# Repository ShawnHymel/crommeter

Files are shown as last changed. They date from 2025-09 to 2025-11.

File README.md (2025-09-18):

# Crommeter SAO

> SHOW ME WHAT YOU GOT

Badge accessory (SAO) to measure general sound level from cheers and applause. Gives a (somewhat) precise measurement of sound pressure level in dB.

This was made in Rust for no other reason than to test my embedded Rust skills.

## Build the Project

To build the project, you'll need Rust on your computer. Follow the [instructions here to install Rust](https://www.rust-lang.org/tools/install).

Next, install the Thumbv8m target processor:

```sh
rustup target add thumbv8m.main-none-eabihf
```

Navigate into the firmware directory and build the project:

```sh
cd firmware/crommeter/
cargo build --release
```

You can either flash the output ELF file (in *target/thumbv8m.main-none-eabihf/release*) using the [Raspberry Pi Debug Probe](https://www.raspberrypi.com/documentation/microcontrollers/debug-probe.html) or you can convert the ELF file to a UF2 file to flash over the USB mass storage device bootloader. To do the latter, you'll need to install [picotool](https://github.com/raspberrypi/picotool).

## (Optional) Install picotool

I recommend downloading one of the pre-compiled releases of picotool from [here](https://github.com/raspberrypi/pico-sdk-tools/releases). Unzip the file somewhere on your computer.

### Windows

Copy the *picotool/* folder to a place like *C:\Program Files\picotool\*.

Update PATH:

 1. Press **Win + R**, type `sysdm.cpl`, press **Enter**
 2. Go to the **Advanced** tab and click **Environment Variables**
 3. Under *User variables* or *System variables*, find *Path*
 4. Click **Edit > New** and add: `C:\Program Files\picotool`
 5. Click **OK** on all dialogs
 6. Restart your terminal/command prompt

### Linux

Copy picotool to your user local bin folder:

```sh
mkdir -p ~/.local/bin
cp picotool ~/.local/bin/
chmod +x ~/.local/bin/picotool
```

Update PATH: add the following to *~/.bashrc*:

```sh
export PATH="$HOME/.local/bin:$PATH"
```

Reload:

```sh
source ~/.bashrc
```

### macOS

Copy picotool to your user local bin folder:

```sh
mkdir -p ~/.local/bin
cp picotool ~/.local/bin/
chmod +x ~/.local/bin/picotool
```

Update PATH: add the following to *~/.zshrc*:

```sh
export PATH="$HOME/.local/bin:$PATH"
```

Reload:

```sh
source ~/.zshrc
```

## Run picotool and Flash

Once you have picotool installed, you can convert the ELF file to a UF2 file. Navigate to the firmware's directory and run:

```sh
cd firmware/crommeter/
picotool uf2 convert target/thumbv8m.main-none-eabihf/release/crommeter -t elf firmware.uf2
```

Hold the BOOT button on the RP2350 stamp and press/release the RESET button while the board is plugged into your computer. That should put the RP2350 into bootloader mode, which enumerates as a mass storage device on your computer. Then, simply copy the *firmware.uf2* file you just created to the RP2350 drive. The board should automatically reset and start running the firmware!

## License

The hardware files are released under [Creative Commons Attribution 4.0 International (CC BY 4.0)](https://creativecommons.org/licenses/by/4.0/).

Code in the firmware directory, unless otherwise noted, is licensed under the [Zero-Clause BSD license](https://opensource.org/license/0bsd) (0BSD).

```
Zero-Clause BSD
=============

Permission to use, copy, modify, and/or distribute this software for
any purpose with or without fee is hereby granted.

THE SOFTWARE IS PROVIDED “AS IS” AND THE AUTHOR DISCLAIMS ALL
WARRANTIES WITH REGARD TO THIS SOFTWARE INCLUDING ALL IMPLIED WARRANTIES
OF MERCHANTABILITY AND FITNESS. IN NO EVENT SHALL THE AUTHOR BE LIABLE
FOR ANY SPECIAL, DIRECT, INDIRECT, OR CONSEQUENTIAL DAMAGES OR ANY
DAMAGES WHATSOEVER RESULTING FROM LOSS OF USE, DATA OR PROFITS, WHETHER IN
AN ACTION OF CONTRACT, NEGLIGENCE OR OTHER TORTIOUS ACTION, ARISING OUT
OF OR IN CONNECTION WITH THE USE OR PERFORMANCE OF THIS SOFTWARE.
```

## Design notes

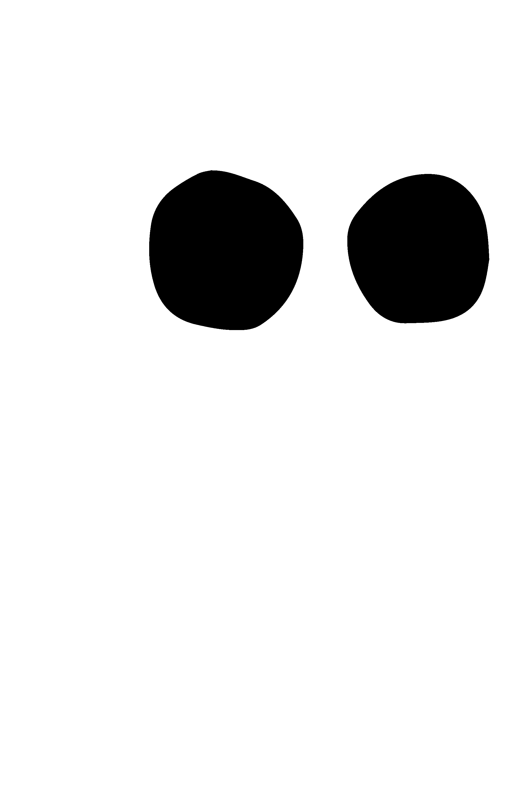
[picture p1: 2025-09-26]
hardware/artwork/cromulon-sm-keepout-bot.png

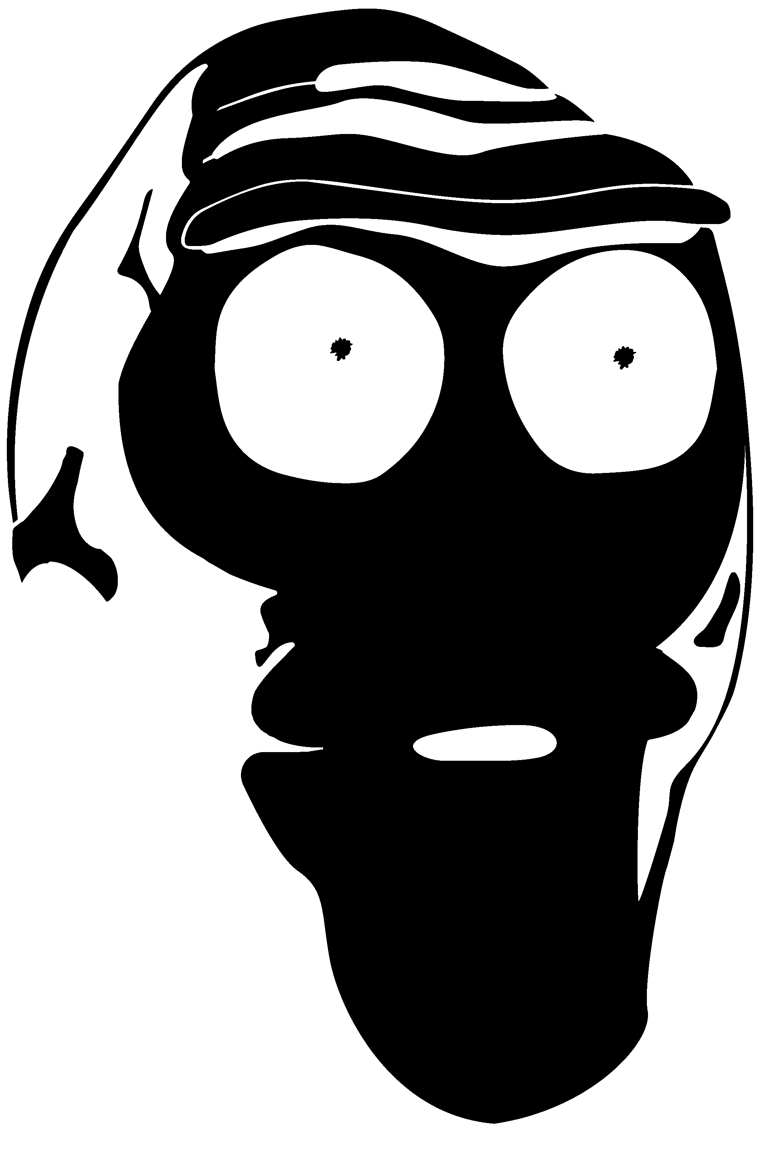
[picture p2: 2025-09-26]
hardware/artwork/cromulon-copper.png

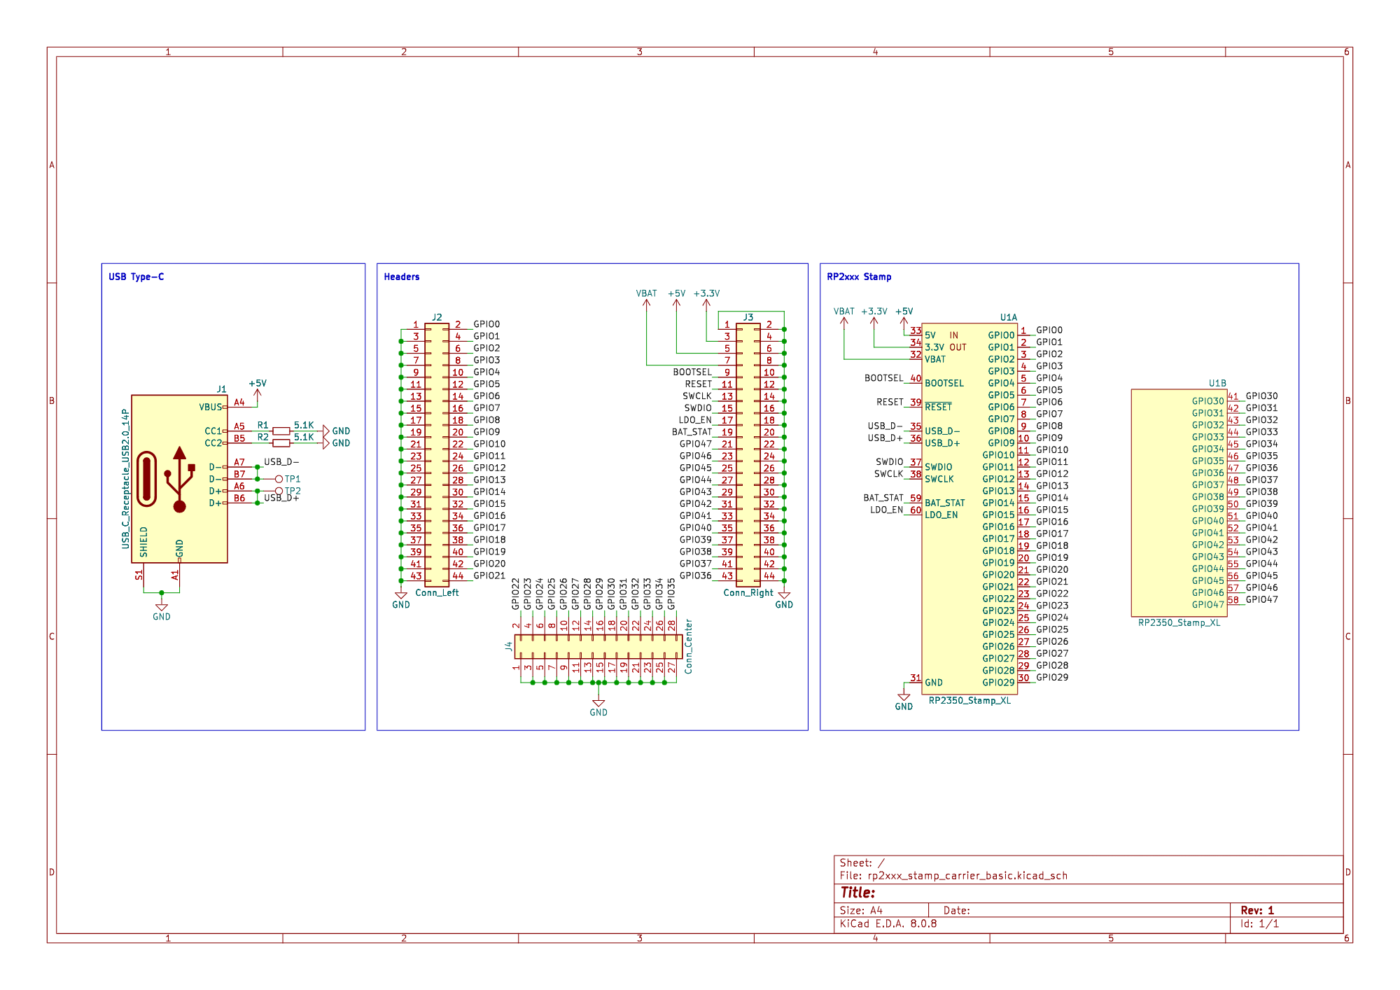
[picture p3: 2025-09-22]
references/rp2xxx-stamp-carrier-basic-schematic.png

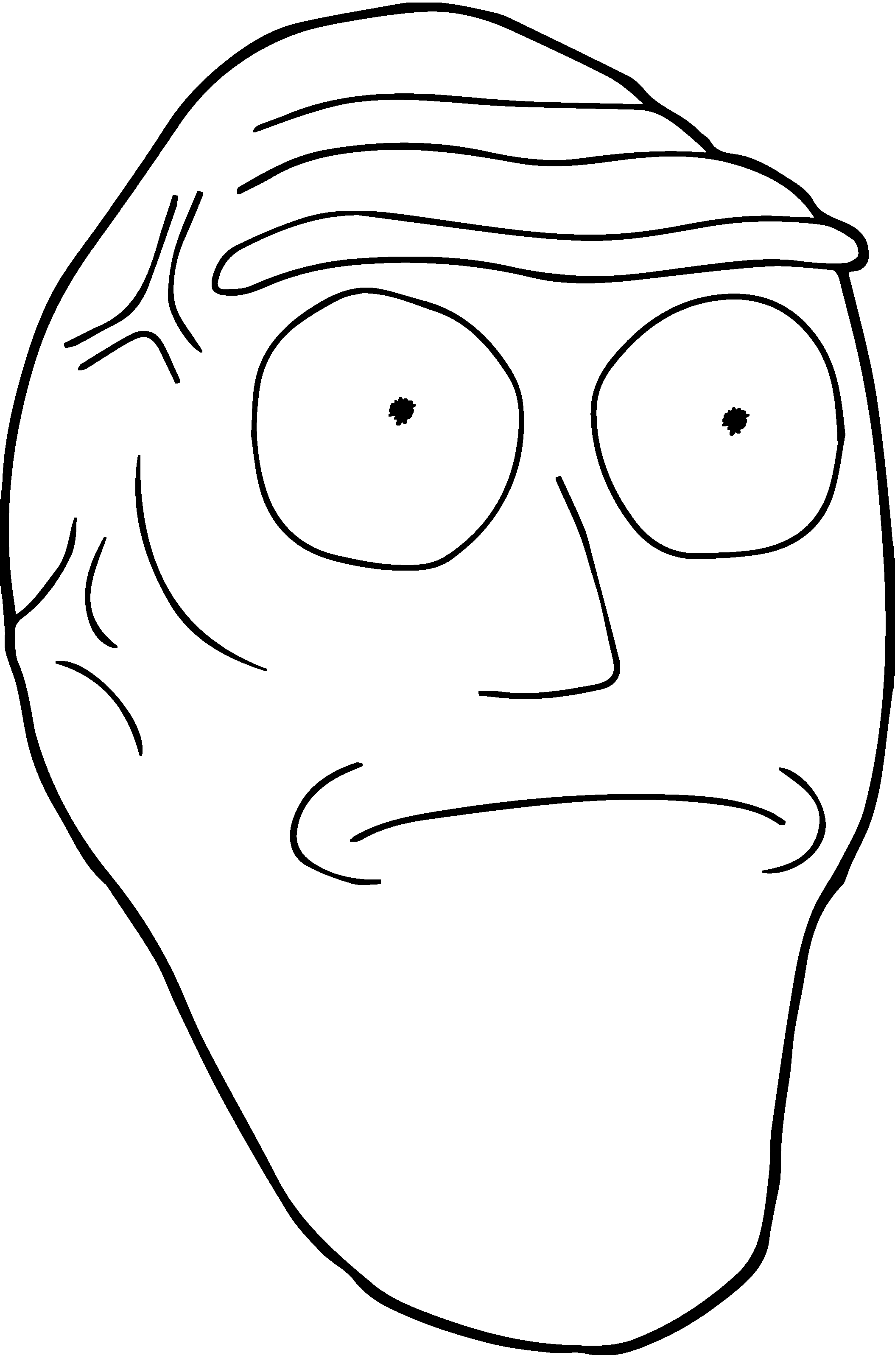
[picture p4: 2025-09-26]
hardware/artwork/cromulon-silkscreen.png

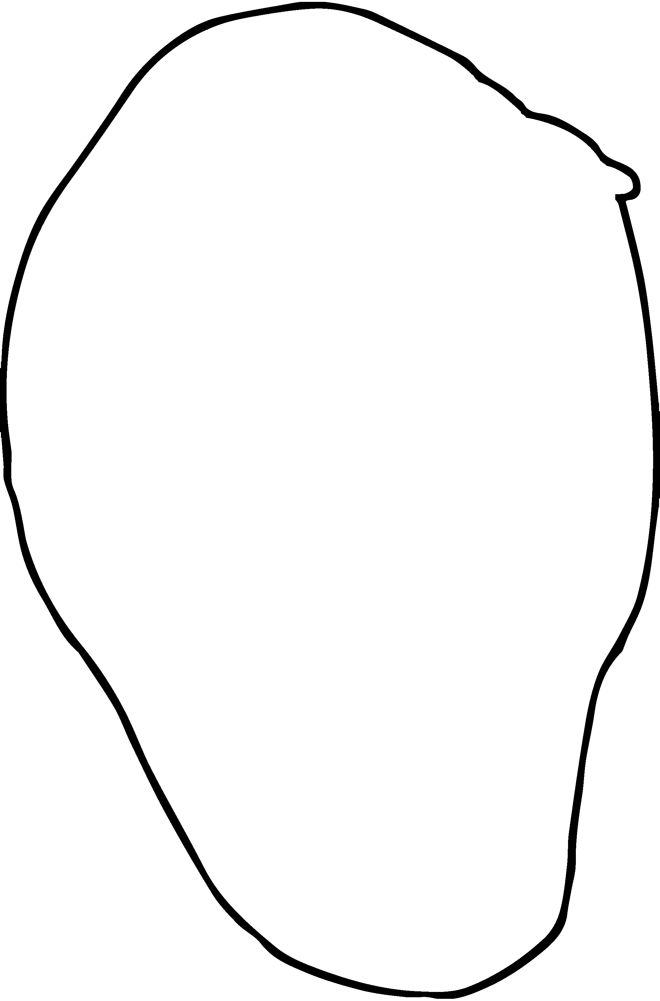
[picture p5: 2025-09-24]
hardware/artwork/cromulon-outline.png

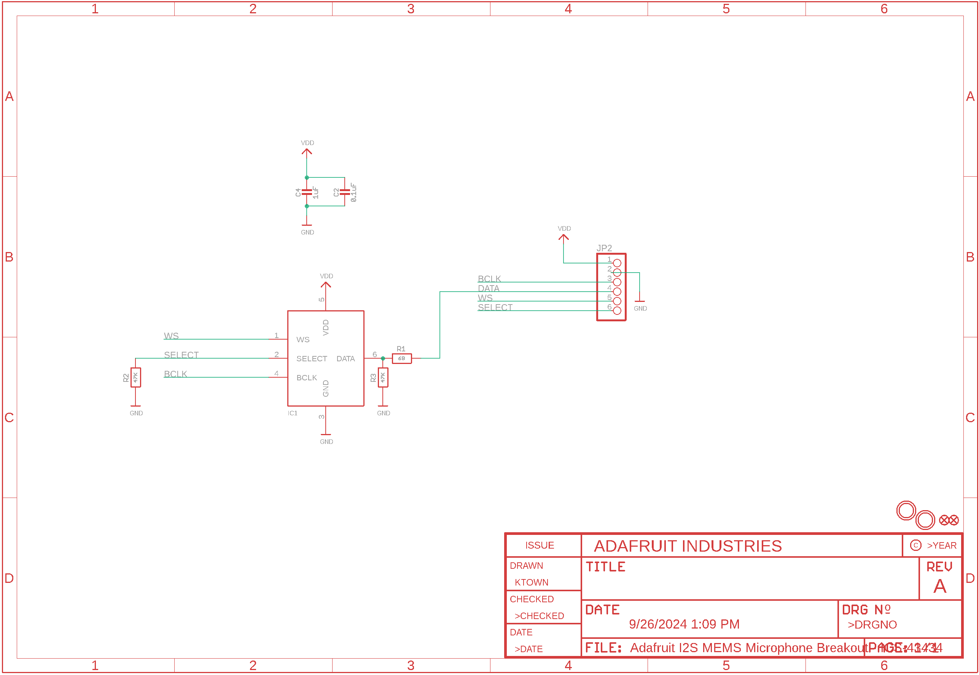
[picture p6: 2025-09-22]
references/adafruit-ics-43434-breakout-schematic.png

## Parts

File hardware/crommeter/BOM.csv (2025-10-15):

Reference | Qty | Value | Footprint | MANUFACTURER | Manufacturer Part Number | Part Link | Footprint Link
C1 | 1 | 0.1uF | Capacitor_SMD:C_0603_1608Metric_Pad1.08x0.95mm_HandSolder | YAGEO | CC0603KRX7R7BB104 | https://www.digikey.com/en/products/detail/yageo/CC0603KRX7R7BB104/302822
C2 | 1 | 1uF | Capacitor_SMD:C_0603_1608Metric_Pad1.08x0.95mm_HandSolder | YAGEO | CC0603KRX7R7BB105 | https://www.digikey.com/en/products/detail/yageo/CC0603KRX7R7BB105/2833611
D1,D2,D3,D4,D5,D6,D7,D8 | 8 | CUW_Y3SH.B2-GFJD-5J6T-Z242-20-R18-Z | CUW_Y3SH_B2_GFJD_5J6T_Z242_20_R18_Z:LED_CUW_Y3SH.B2-GFJD-5J6T-Z242-20-R18-Z | OSRAM Opto Semiconductors Inc. | CUW Y3SH.B2-GFJD-5J6T-Z242-20-R18-Z | https://www.digikey.com/en/products/detail/ams-osram-usa-inc/CUW-Y3SH-B2-GFJD-5J6T-Z242-20-R18-Z/13998110 | https://www.digikey.com/en/models/13998110
H1 | 1 | MountingHole | MountingHole:MountingHole_4.3mm_M4
J1 | 1 | 10118194-0001LF | 10118194_0001LF:AMPHENOL_10118194-0001LF | Amphenol | 10118194-0001LF | https://www.digikey.com/en/products/detail/amphenol-cs-fci/10118194-0001LF/2785389 | https://www.digikey.com/en/models/2785389
J2 | 1 | Conn_01x03_Pin | 10129380-903001BLF:AMPHENOL_10129380-903001BLF | Amphenol ICC (FCI) | 10129380-903001BLF | https://www.digikey.com/en/products/detail/amphenol-cs-fci/10129380-903001BLF/7916034 | https://www.digikey.com/en/models/7916034
J3 | 1 | PRT-14417 | qwiic_connector:CONN_PRT-14417_SPK | SparkFun Electronics | 14417 | https://www.digikey.com/en/products/detail/sparkfun-electronics/14417/7652746 | https://www.digikey.com/en/models/7652746
MK1 | 1 | ICS-43434 | Sensor_Audio:InvenSense_ICS-43434-6_3.5x2.65mm | TDK InvenSense | ICS-43434 | https://www.digikey.com/en/products/detail/tdk-invensense/ICS-43434/6140298 | https://www.digikey.com/en/models/6140298
P1 | 1 | S2B-PH-SM4-TB | S2B-PH-SM4-TB:JST_S2B-PH-SM4-TB | JST | S2B-PH-SM4-TB | https://www.digikey.com/en/products/detail/jst-sales-america-inc/S2B-PH-SM4-TB/926655 | https://www.digikey.com/en/models/926655
Q1,Q2,Q3 | 3 | BSD840NH6327XTSA1 | BSD840NH6327XTSA1:TRANS_BSD840NH6327XTSA1 | INFINEON | BSD840NH6327XTSA1 | https://www.digikey.com/en/products/detail/infineon-technologies/BSD840NH6327XTSA1/2783455 | https://www.digikey.com/en/models/2783455
R1 | 1 | 47k | Resistor_SMD:R_0603_1608Metric_Pad0.98x0.95mm_HandSolder | YAGEO | RC0603FR-0747KL | https://www.digikey.com/en/products/detail/yageo/RC0603FR-0747KL/727253
R2 | 1 | 68 | Resistor_SMD:R_0603_1608Metric_Pad0.98x0.95mm_HandSolder | YAGEO | RC0603FR-0768RL | https://www.digikey.com/en/products/detail/yageo/RC0603FR-0768RL/727351
R3,R4,R5,R6,R7,R8,R9,R10 | 8 | 120 | Resistor_SMD:R_0603_1608Metric_Pad0.98x0.95mm_HandSolder | YAGEO | RC0603JR-7W120RL | https://www.digikey.com/en/products/detail/yageo/RC0603JR-7W120RL/12698837
R11,R13,R15,R21,R27 | 5 | 100 | Resistor_SMD:R_0603_1608Metric_Pad0.98x0.95mm_HandSolder | YAGEO | RC0603FR-7W100RL | https://www.digikey.com/en/products/detail/yageo/RC0603FR-7W100RL/12698887
R12,R14,R16,R22,R28 | 5 | 100k | Resistor_SMD:R_0603_1608Metric_Pad0.98x0.95mm_HandSolder | YAGEO | RC0603FR-07100KL | https://www.digikey.com/en/products/detail/yageo/RC0603FR-07100KL/726889
R17,R18,R19,R20,R23,R24,R25,R26 | 8 | 47 | Resistor_SMD:R_0603_1608Metric_Pad0.98x0.95mm_HandSolder | YAGEO | RC0603FR-1347RL | https://www.digikey.com/en/products/detail/yageo/RC0603FR-1347RL/13694193
R29,R30,R31 | 3 | DNP | Resistor_SMD:R_0603_1608Metric_Pad0.98x0.95mm_HandSolder
SW1 | 1 | SW_Push_Dual | FSM2JSMAATR:SWITCH_FSM2JSMAA_TYC | TE Connectivity ALCOSWITCH Switches | FSM2JSMAATR | https://www.digikey.com/en/products/detail/te-connectivity-alcoswitch-switches/FSM2JSMAATR/1201469 | https://www.digikey.com/en/models/1201469
U1 | 1 | RP2350_Stamp | RP2xxx_Stamp:RP2xxx_Stamp_SMD | Solder Party | RP2350 Stamp | https://shop.pimoroni.com/products/rp2350-stamp | https://github.com/solderparty/rp2xxx_stamp_footprints
U2 | 1 | Common Cathode | custom:SDTx40R2W | ChromeLED | SDTC40R2W | https://www.digikey.com/en/products/detail/chromeled/SDTC40R2W/12698561
X1 | 1 | Badgelife_sao_connector_v169bis | badgelife_sao_v169bis:Badgelife-SAOv169-SAO-2x3 | Adam Tech | BHR-06-VUA | https://www.digikey.com/en/products/detail/adam-tech/BHR-06-VUA/10414837 | https://cdn.hackaday.io/files/1751827494986688/KiCad_SAOv2.zip

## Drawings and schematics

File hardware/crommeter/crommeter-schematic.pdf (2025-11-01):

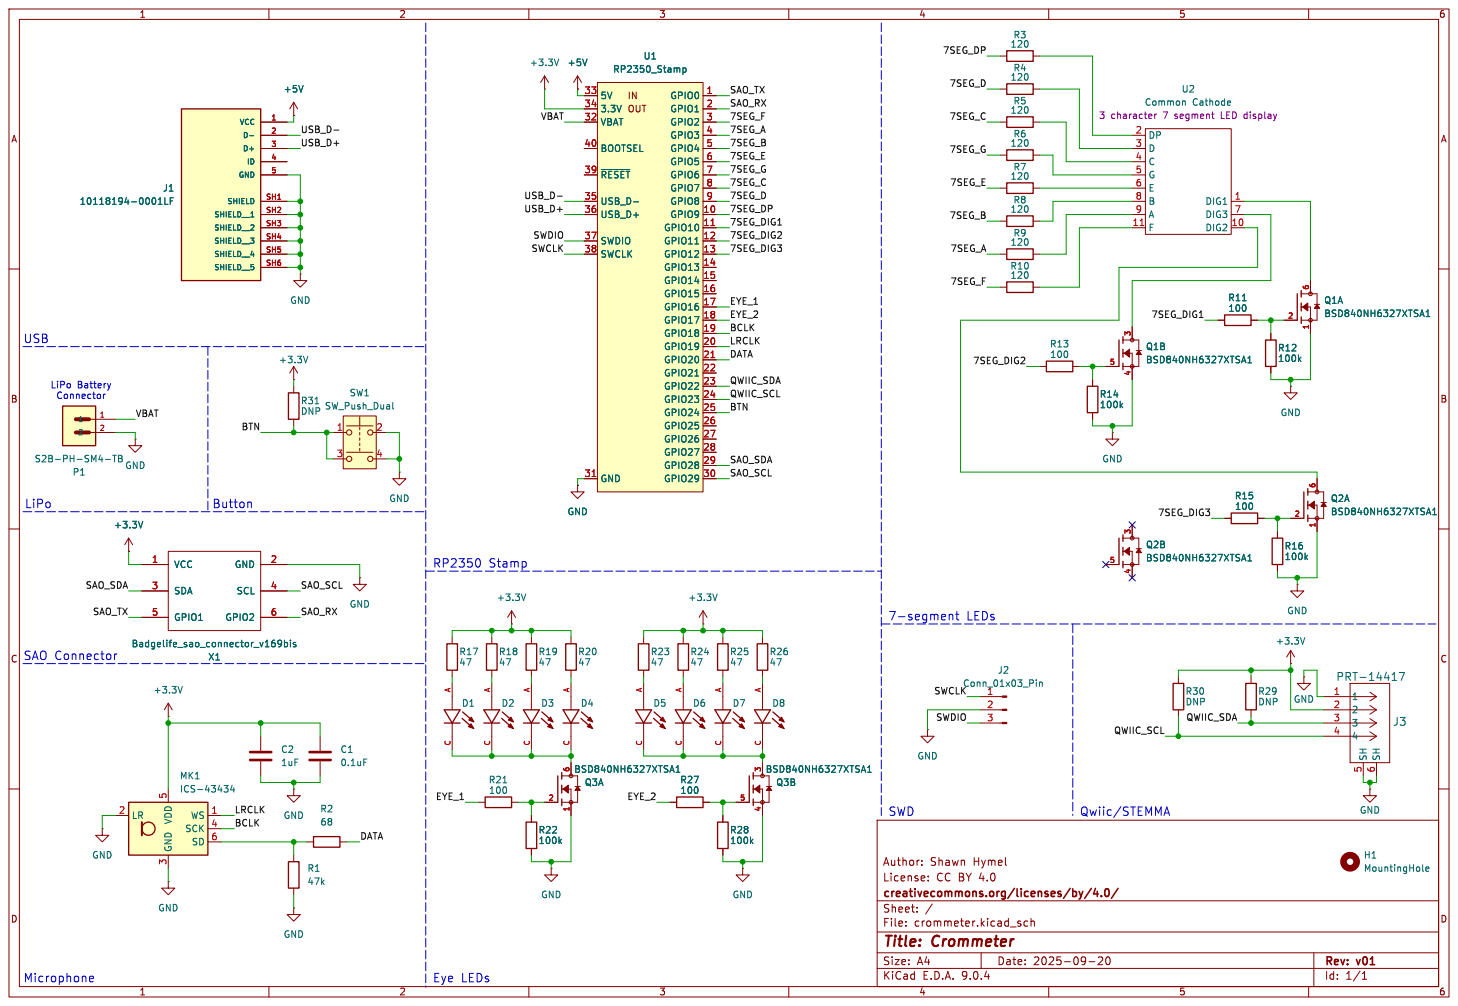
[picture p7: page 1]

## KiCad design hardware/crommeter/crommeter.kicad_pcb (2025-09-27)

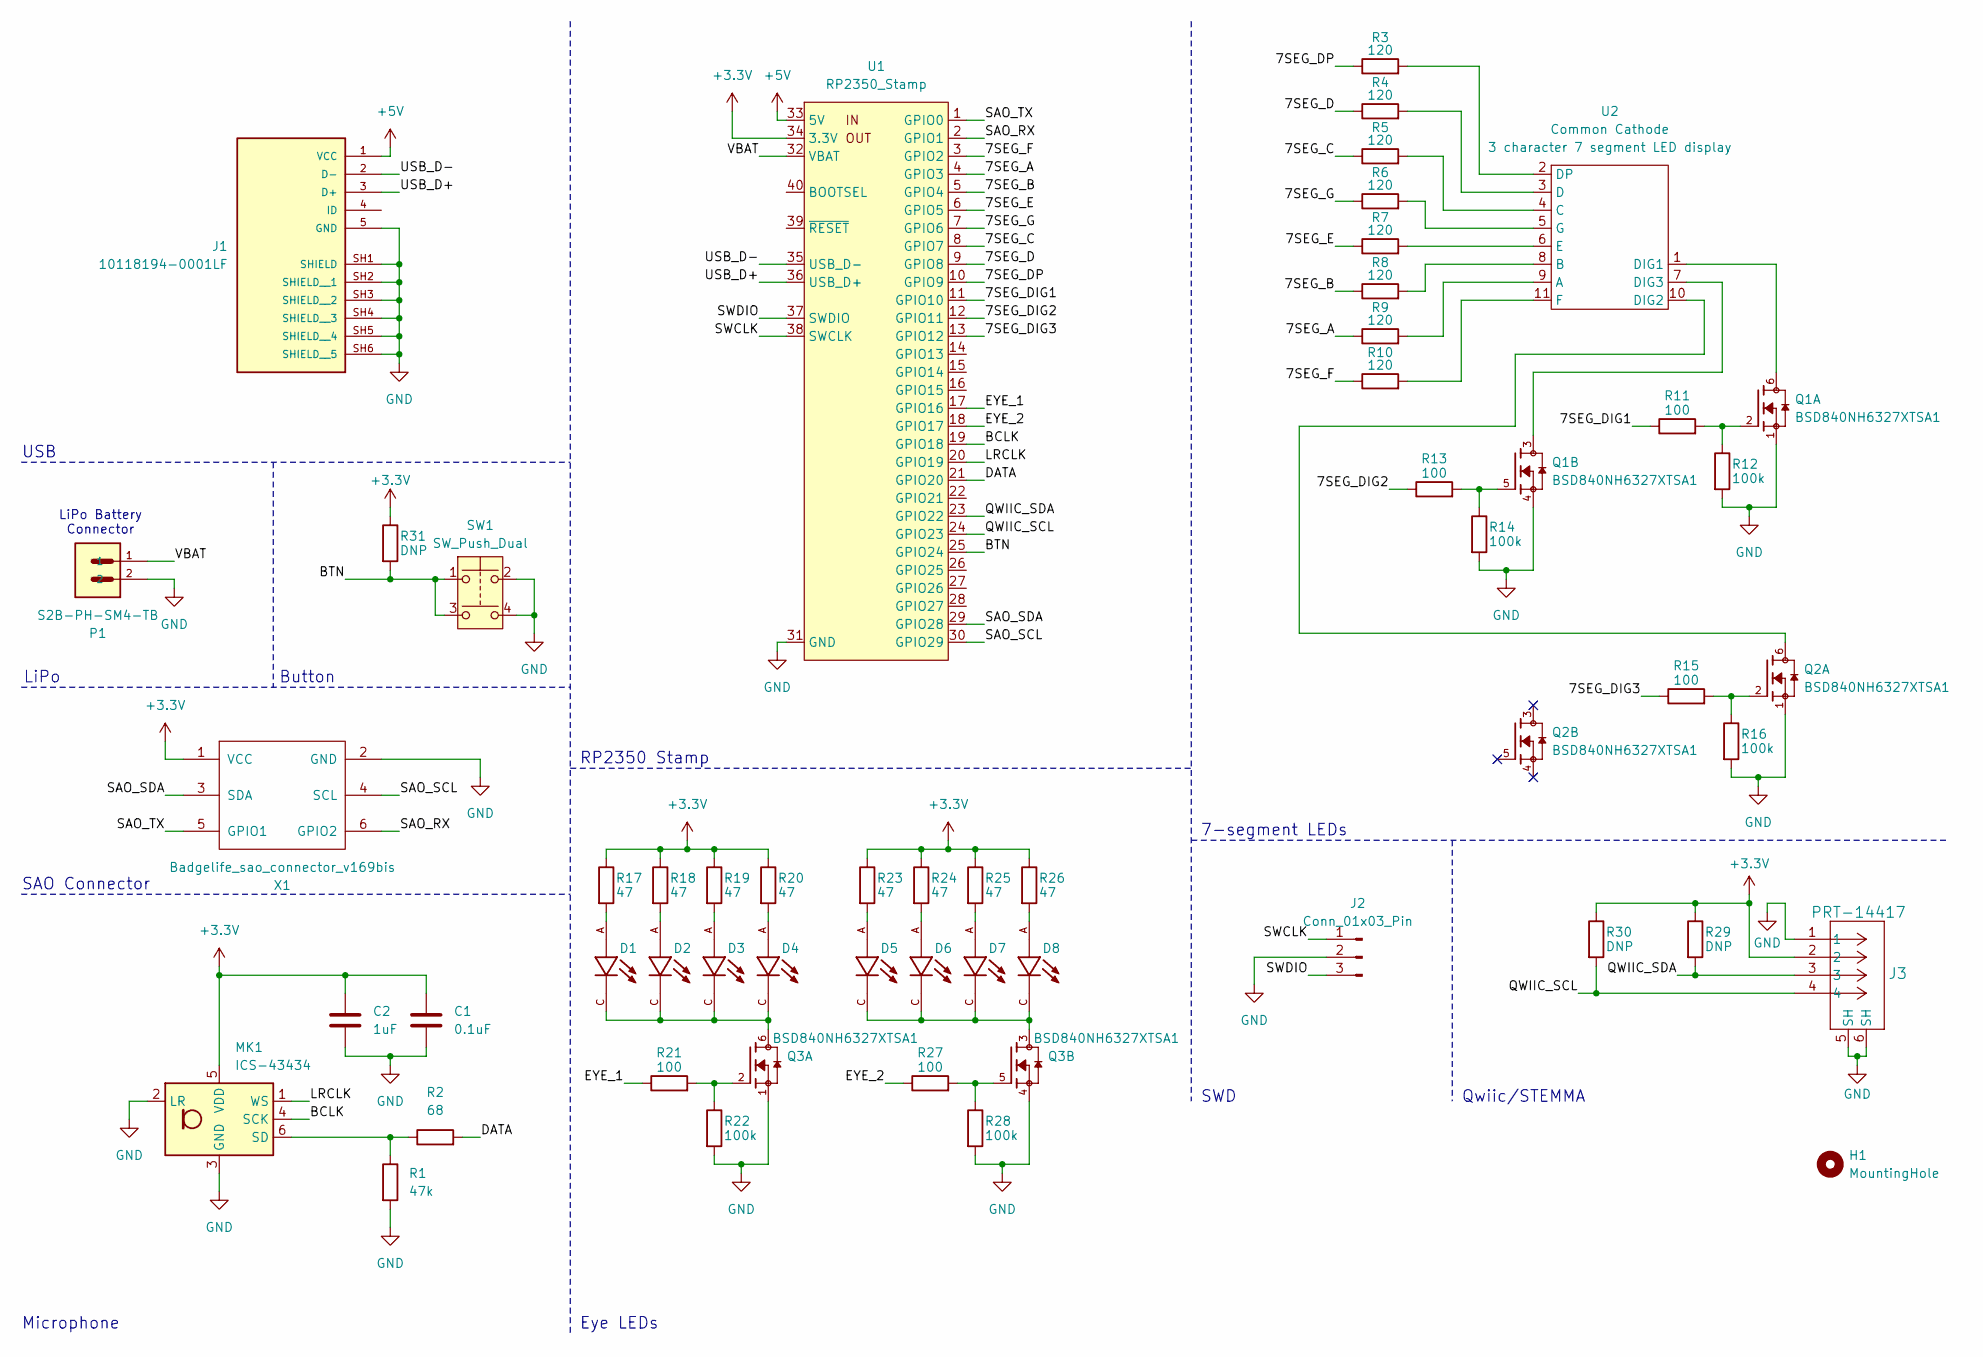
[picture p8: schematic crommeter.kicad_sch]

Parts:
C1: 0.1uF; C_0603_1608Metric_Pad1.08x0.95mm_HandSolder
C2: 1uF; C_0603_1608Metric_Pad1.08x0.95mm_HandSolder
D1, D2, D3, D4, D5, D6, D7, D8: CUW_Y3SH.B2-GFJD-5J6T-Z242-20-R18-Z; LED_CUW_Y3SH.B2-GFJD-5J6T-Z242-20-R18-Z; PARTREV 1.0
H1: MountingHole; MountingHole_4.3mm_M4
J1: 10118194-0001LF; AMPHENOL_10118194-0001LF; PARTREV D
J2: Conn_01x03_Pin; AMPHENOL_10129380-903001BLF
J3: PRT-14417; CONN_PRT-14417_SPK
MK1: ICS-43434; InvenSense_ICS-43434-6_3.5x2.65mm
P1: S2B-PH-SM4-TB; JST_S2B-PH-SM4-TB
Q1, Q2, Q3: BSD840NH6327XTSA1; TRANS_BSD840NH6327XTSA1; PARTREV 2.4
R1: 47k; R_0603_1608Metric_Pad0.98x0.95mm_HandSolder
R2: 68; R_0603_1608Metric_Pad0.98x0.95mm_HandSolder
R3, R4, R5, R6, R7, R8, R9, R10: 120; R_0603_1608Metric_Pad0.98x0.95mm_HandSolder
R11, R13, R15, R21, R27: 100; R_0603_1608Metric_Pad0.98x0.95mm_HandSolder
R12, R14, R16, R22, R28: 100k; R_0603_1608Metric_Pad0.98x0.95mm_HandSolder
R17, R18, R19, R20, R23, R24, R25, R26: 47; R_0603_1608Metric_Pad0.98x0.95mm_HandSolder
R29, R30, R31: DNP; R_0603_1608Metric_Pad0.98x0.95mm_HandSolder
SW1: SW_Push_Dual; SWITCH_FSM2JSMAA_TYC
U1: RP2350_Stamp; RP2xxx_Stamp_SMD
U2: Common Cathode; SDTx40R2W
X1: Badgelife_sao_connector_v169bis; Badgelife-SAOv169-SAO-2x3

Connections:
+3.3V: C1.1, C2.1, J3.2, MK1.5 (VDD), R17.1, R18.1, R19.1, R20.1, R23.1, R24.1, R25.1, R26.1, R29.1, R30.1, R31.1, U1.34 (3.3V), X1.1 (VCC)
+5V: J1.1 (VCC), U1.33 (5V)
/7SEG_A: R9.1, U1.4 (GPIO3)
/7SEG_B: R8.1, U1.5 (GPIO4)
/7SEG_C: R5.1, U1.8 (GPIO7)
/7SEG_D: R4.1, U1.9 (GPIO8)
/7SEG_DIG1: R11.1, U1.11 (GPIO10)
/7SEG_DIG2: R13.1, U1.12 (GPIO11)
/7SEG_DIG3: R15.1, U1.13 (GPIO12)
/7SEG_DP: R3.1, U1.10 (GPIO9)
/7SEG_E: R7.1, U1.6 (GPIO5)
/7SEG_F: R10.1, U1.3 (GPIO2)
/7SEG_G: R6.1, U1.7 (GPIO6)
/<NO NET>: U1.29 (GPIO28), X1.3 (SDA)
/BCLK: MK1.4 (SCK), U1.19 (GPIO18)
/BTN: R31.2, SW1.1, SW1.3, U1.25 (GPIO24)
/DATA: R2.2, U1.21 (GPIO20)
/EYE_1: R21.1, U1.17 (GPIO16)
/EYE_2: R27.1, U1.18 (GPIO17)
/LRCLK: MK1.1 (WS), U1.20 (GPIO19)
/QWIIC_SCL: J3.4, R30.2, U1.24 (GPIO23)
/QWIIC_SDA: J3.3, R29.2, U1.23 (GPIO22)
/SAO_RX: U1.2 (GPIO1), X1.6 (GPIO2)
/SAO_SCL: U1.30 (GPIO29), X1.4 (SCL)
/SAO_TX: U1.1 (GPIO0), X1.5 (GPIO1)
/SWCLK: J2.1, U1.38 (SWCLK)
/SWDIO: J2.3, U1.37 (SWDIO)
/USB_D+: J1.3 (D+), U1.36 (USB_D+)
/USB_D-: J1.2 (D-), U1.35 (USB_D-)
/VBAT: P1.1, U1.32 (VBAT)
GND: C1.2, C2.2, J1.5 (GND), J1.SH1 (SHIELD), J1.SH2 (SHIELD__1), J1.SH3 (SHIELD__2), J1.SH4 (SHIELD__3), J1.SH5 (SHIELD__4), J1.SH6 (SHIELD__5), J2.2, J3.1, J3.5 (SH), J3.6 (SH), MK1.2 (LR), MK1.3 (GND), P1.2, Q1.1, Q1.4, Q2.1, Q3.1, Q3.4, R1.2, R12.2, R14.2, R16.2, R22.2, R28.2, SW1.2, SW1.4, U1.31 (GND), X1.2 (GND)
unnamed: D1.A, R17.2
unnamed: D1.C, D2.C, D3.C, D4.C, Q3.6
unnamed: D2.A, R18.2
unnamed: D3.A, R19.2
unnamed: D4.A, R20.2
unnamed: D5.A, R23.2
unnamed: D5.C, D6.C, D7.C, D8.C, Q3.3
unnamed: D6.A, R24.2
unnamed: D7.A, R25.2
unnamed: D8.A, R26.2
unnamed: MK1.6 (SD), R1.1, R2.1
unnamed: Q1.2, R11.2, R12.1
unnamed: Q1.5, R13.2, R14.1
unnamed: Q2.2, R15.2, R16.1
unnamed: Q3.2, R21.2, R22.1
unnamed: Q3.5, R27.2, R28.1
unnamed: R9.2, U2.9 (A)
unnamed: R8.2, U2.8 (B)
unnamed: R5.2, U2.4 (C)
unnamed: R4.2, U2.3 (D)
unnamed: Q1.6, U2.1 (DIG1)
unnamed: Q2.6, U2.10 (DIG2)
unnamed: Q1.3, U2.7 (DIG3)
unnamed: R3.2, U2.2 (DP)
unnamed: R7.2, U2.6 (E)
unnamed: R10.2, U2.11 (F)
unnamed: R6.2, U2.5 (G)

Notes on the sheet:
7-segment LEDs
RP2350 Stamp
Microphone
USB
LiPo Battery Connector
Eye LEDs
Button
Qwiic/STEMMA
LiPo
SAO Connector
SWD

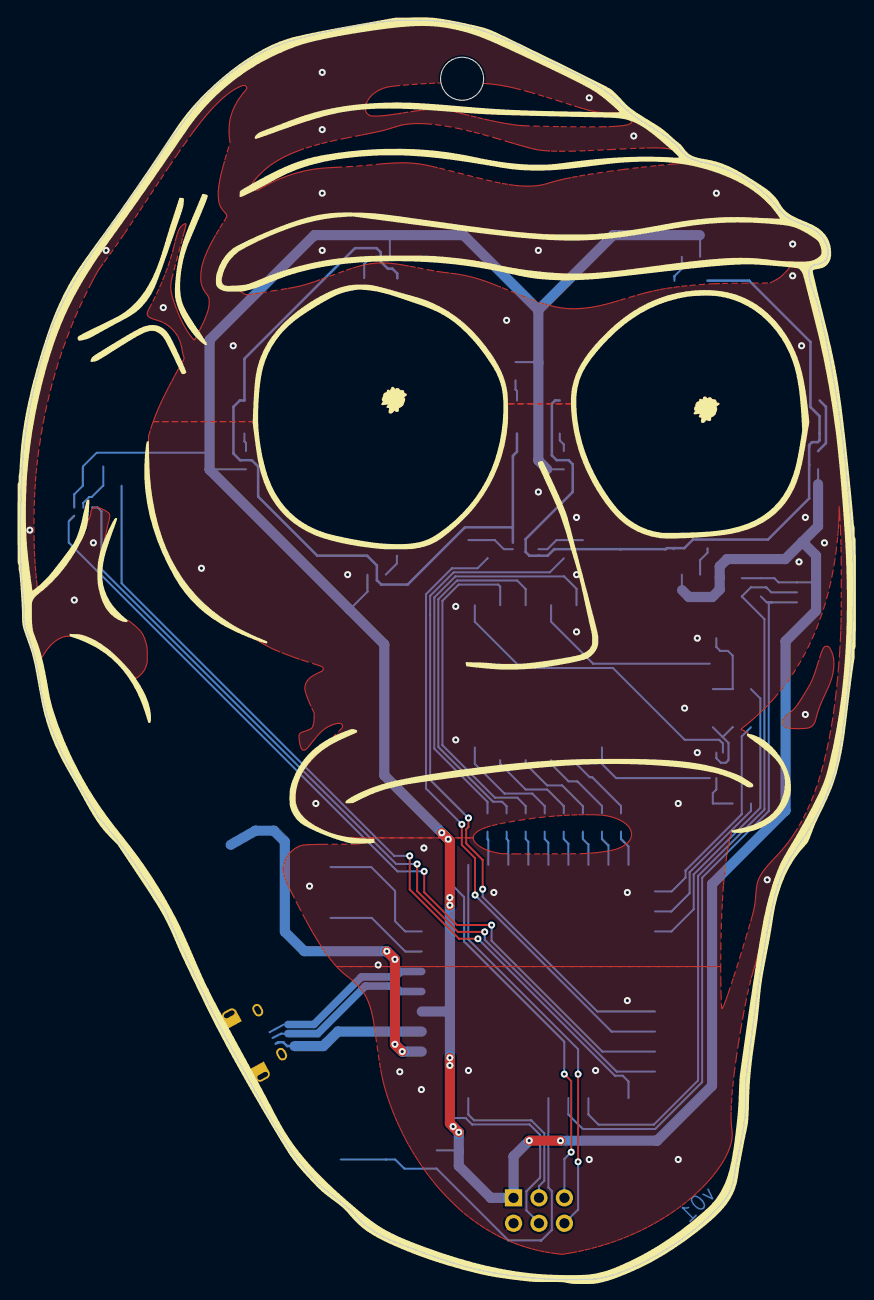
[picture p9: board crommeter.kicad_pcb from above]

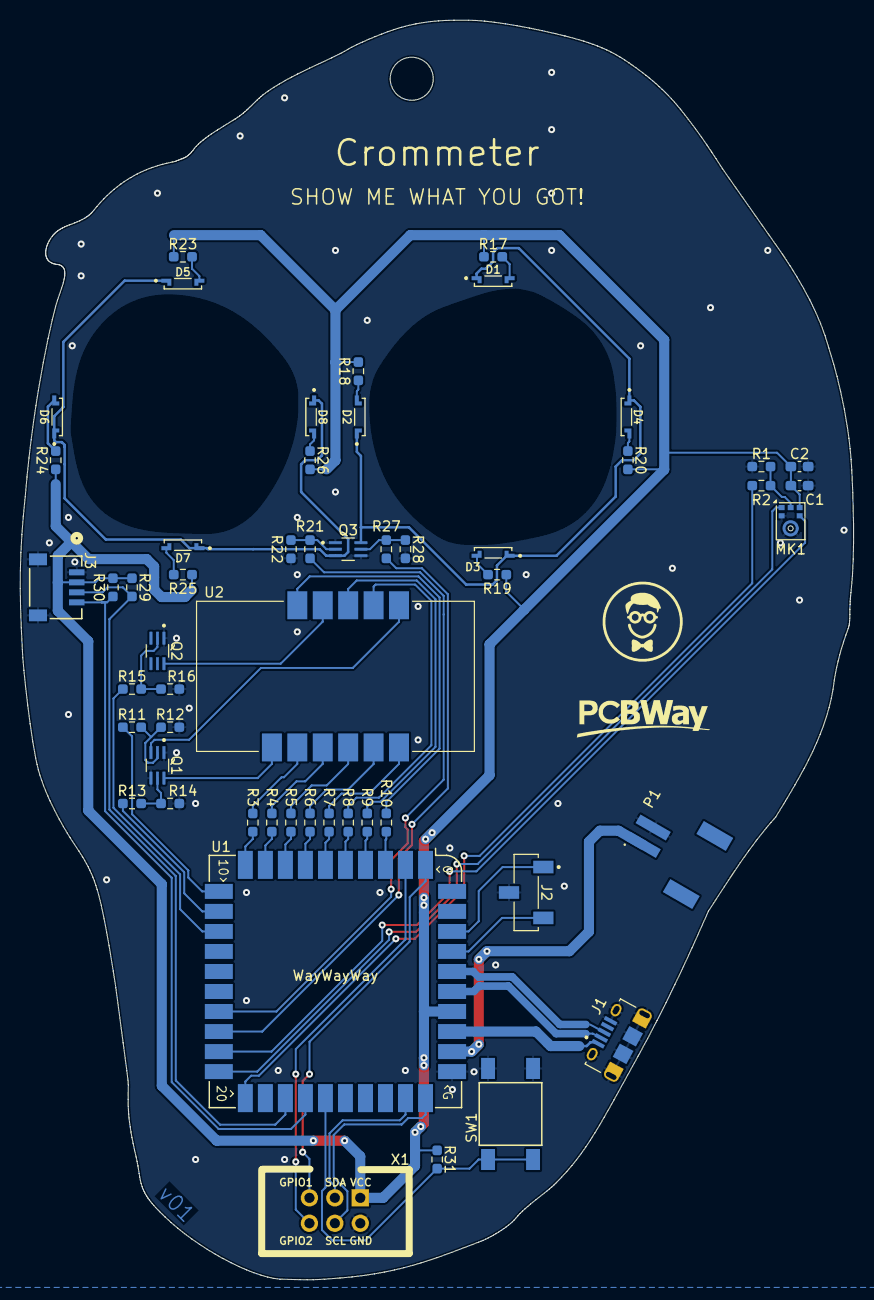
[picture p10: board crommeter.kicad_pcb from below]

Board: 4 copper layers, 83.2 x 125.8 mm, 54 parts (52 on the bottom side), 58 nets.

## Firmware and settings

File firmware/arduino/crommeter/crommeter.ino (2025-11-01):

#include <math.h>

#include <hardware/timer.h>
#include <hardware/irq.h>
#include <I2S.h>

/******************************************************************************
 * Pins
 */

// Toggle debug
#define DEBUG_ENABLE  1

// LED and button
#define LED_PIN       29
#define BTN_PIN       24

// I2S pins
#define I2S_DATA_PIN  20
#define I2S_BCLK_PIN  18  // Note that LRCLK is set to BCLK + 1

// 7-segment display pins
#define SEG_A         3
#define SEG_B         4
#define SEG_C         7
#define SEG_D         8
#define SEG_E         5
#define SEG_F         2
#define SEG_G         6
#define SEG_DP        9
#define DIGIT_1       10
#define DIGIT_2       12
#define DIGIT_3       11

// Eye LED pins
#define EYE_L_PIN     17
#define EYE_R_PIN     16

/******************************************************************************
 * Settings
 */

// Audio settings
#define SERIAL_BAUD_RATE  115200
#define SAMPLE_RATE       16000
#define BITS_PER_SAMPLE   32
#define BUFFER_SIZE       256
#define NUM_BUFFERS       6

// dB calculation settings
#define UPDATE_INTERVAL_MS  200  // Calculate dB every 0.5 seconds
#define BUFFERS_PER_UPDATE  13   // ~500ms worth of buffers (500ms / 16ms per buffer)

// dB range for LED brightness calculation
#define MIN_DB 40.0
#define MAX_DB 120.0

// ICS-43434 sensitivity: -26 dBFS at 94 dB SPL
#define MIC_SENSITIVITY_DBFS  -26.0
#define MIC_REF_DB_SPL        94.0
#define MIC_OFFSET_DB         (MIC_REF_DB_SPL - MIC_SENSITIVITY_DBFS)  // = 120 dB

// Full scale reference for 32-bit samples
// ICS-43434 outputs 24-bit left-aligned in 32-bit = max value around 2^31
#define FULL_SCALE_32BIT  2147483648.0  // 2^31

// Timer configuration
#define DISPLAY_REFRESH_RATE  60   // Hz - full display refresh rate
#define DIGIT_UPDATE_RATE     (DISPLAY_REFRESH_RATE * 3)  // 60 Hz per digit

// Peak recording mode
#define DEBOUNCE_DELAY_MS     50
#define PEAK_DISPLAY_HOLD_MS  2000  // How long (ms) to hold display with peak value

/******************************************************************************
 * Macros
 */

#if DEBUG_ENABLE
  #define DEBUG_BEGIN(baud)     Serial.begin(baud)
  #define DEBUG(...)            Serial.printf(__VA_ARGS__)
#else
  #define DEBUG_BEGIN(baud)     // Do nothing
  #define DEBUG(...)            // Do nothing
#endif

/******************************************************************************
 * Globals
 */

// 7-segment digit encoding (common cathode, adjust for common anode)
// Segments: ABCDEFG (bit 7=DP, bits 6-0 = GFEDCBA)
const uint8_t DIGIT_PATTERNS[11] = {
  0b00111111,  // 0
  0b00000110,  // 1
  0b01011011,  // 2
  0b01001111,  // 3
  0b01100110,  // 4
  0b01101101,  // 5
  0b01111101,  // 6
  0b00000111,  // 7
  0b01111111,  // 8
  0b01101111,  // 9
  0b01000000   // -
};

// Double buffer for display data
volatile uint8_t displayBuffer[2][3];  // [buffer][digit]
volatile uint8_t activeBuffer = 0;     // Which buffer ISR is reading from
volatile uint8_t writeBuffer = 1;      // Which buffer main code writes to

// Hardware timer for display refresh
struct repeating_timer displayTimer;

// ISR state
volatile uint8_t currentDigit = 0;     // Which digit (0-2) is currently lit

// I2S input object
I2S i2s(INPUT);

// Buffer for processing
volatile bool bufferReady = false;
int32_t processingBuffer[BUFFER_SIZE * 2];  // *2 for stereo (L+R)

// RMS accumulation
uint64_t sumOfSquares = 0;
uint32_t samplesAccumulated = 0;
uint32_t buffersAccumulated = 0;
unsigned long lastUpdateTime = 0;

// Peak recording mode
double peakDbSPL = 0.0;

// Debounce
bool buttonState;
bool lastButtonReading = HIGH;
unsigned long lastDebounceTime = 0;

// Display time
unsigned long displayTime = 0;

// State
unsigned int mode = 0;

/******************************************************************************
 * Interrupt service routines
 */

// Notify that I2S buffer is ready
void onI2SReceive() {
  bufferReady = true;
}

// 7-segment display driver
bool __isr __time_critical_func(displayTimerCallback)(struct repeating_timer *t) {
  // Turn off all digits first to prevent ghosting
  digitalWrite(DIGIT_1, LOW);
  digitalWrite(DIGIT_2, LOW);
  digitalWrite(DIGIT_3, LOW);
  
  // Get the pattern for current digit from active buffer
  uint8_t pattern = displayBuffer[activeBuffer][currentDigit];
  
  // Output the segment pattern
  digitalWrite(SEG_A, (pattern & 0b00000001) ? HIGH : LOW);
  digitalWrite(SEG_B, (pattern & 0b00000010) ? HIGH : LOW);
  digitalWrite(SEG_C, (pattern & 0b00000100) ? HIGH : LOW);
  digitalWrite(SEG_D, (pattern & 0b00001000) ? HIGH : LOW);
  digitalWrite(SEG_E, (pattern & 0b00010000) ? HIGH : LOW);
  digitalWrite(SEG_F, (pattern & 0b00100000) ? HIGH : LOW);
  digitalWrite(SEG_G, (pattern & 0b01000000) ? HIGH : LOW);
  // digitalWrite(SEG_DP, (pattern & 0b10000000) ? HIGH : LOW);  // Optional
  
  // Turn on the current digit
  switch(currentDigit) {
    case 0: digitalWrite(DIGIT_1, HIGH); break;
    case 1: digitalWrite(DIGIT_2, HIGH); break;
    case 2: digitalWrite(DIGIT_3, HIGH); break;
  }
  
  // Move to next digit
  currentDigit++;
  if (currentDigit >= 3) {
    currentDigit = 0;
  }
  
  return true;  // Keep the timer running
}

/******************************************************************************
 * Functions
 */

void setupDisplay() {
  // Configure segment pins as outputs
  pinMode(SEG_A, OUTPUT);
  pinMode(SEG_B, OUTPUT);
  pinMode(SEG_C, OUTPUT);
  pinMode(SEG_D, OUTPUT);
  pinMode(SEG_E, OUTPUT);
  pinMode(SEG_F, OUTPUT);
  pinMode(SEG_G, OUTPUT);
  pinMode(SEG_DP, OUTPUT);
  
  // Configure digit select pins as outputs
  pinMode(DIGIT_1, OUTPUT);
  pinMode(DIGIT_2, OUTPUT);
  pinMode(DIGIT_3, OUTPUT);
  
  // Turn off all digits initially
  digitalWrite(DIGIT_1, LOW);
  digitalWrite(DIGIT_2, LOW);
  digitalWrite(DIGIT_3, LOW);
  
  // Initialize buffers to show "000"
  for (int buf = 0; buf < 2; buf++) {
    for (int dig = 0; dig < 3; dig++) {
      displayBuffer[buf][dig] = DIGIT_PATTERNS[0];
    }
  }
  
  // Start the timer - fires every 1000000/180 = ~5555 microseconds
  int64_t intervalUs = 1000000 / DIGIT_UPDATE_RATE;
  add_repeating_timer_us(-intervalUs, displayTimerCallback, NULL, &displayTimer);
}

void swapBuffers() {
  // Swap buffers atomically
  noInterrupts();
  uint8_t temp = activeBuffer;
  activeBuffer = writeBuffer;
  writeBuffer = temp;
  interrupts();
}

void updateDisplay(int value) {
  // Clamp value to 0-999
  if (value < 0) value = 0;
  if (value > 999) value = 999;
  
  // Extract individual digits
  uint8_t digit0 = (value / 100) % 10;      // Hundreds
  uint8_t digit1 = (value / 10) % 10;       // Tens
  uint8_t digit2 = value % 10;              // Ones
  
  // Write to the inactive buffer
  displayBuffer[writeBuffer][0] = DIGIT_PATTERNS[digit0];
  displayBuffer[writeBuffer][1] = DIGIT_PATTERNS[digit1];
  displayBuffer[writeBuffer][2] = DIGIT_PATTERNS[digit2];
  
  swapBuffers();
}

void displayDashes() {
  // Write dashes to the inactive buffer
  displayBuffer[writeBuffer][0] = DIGIT_PATTERNS[10];
  displayBuffer[writeBuffer][1] = DIGIT_PATTERNS[10];
  displayBuffer[writeBuffer][2] = DIGIT_PATTERNS[10];
  
  swapBuffers();
}

uint8_t dbToPWM(double dbSPL) {  
  // Clamp input
  if (dbSPL < MIN_DB) dbSPL = MIN_DB;
  if (dbSPL > MAX_DB) dbSPL = MAX_DB;
  
  // Linear mapping in dB space
  double normalized = (dbSPL - MIN_DB) / (MAX_DB - MIN_DB);
  
  // Exponential brightness curve: y = e^(x*k) - 1 / (e^k - 1)
  // This gives more dynamic range at lower sound levels
  const double k = 3.0;  // Adjust for more/less emphasis on low levels
  double corrected = (exp(normalized * k) - 1.0) / (exp(k) - 1.0);
  
  // Scale to PWM range
  uint8_t pwmValue = (uint8_t)(corrected * 255.0);
  
  return pwmValue;
}

/******************************************************************************
 * Main
 */

void setup() {
  // Initialize LED pin
  pinMode(LED_PIN, OUTPUT);

  // Initialize eyes
  pinMode(EYE_L_PIN, OUTPUT);
  pinMode(EYE_R_PIN, OUTPUT);

  // Setup button with pullup and interrupt
  pinMode(BTN_PIN, INPUT_PULLUP);

  // Initialize serial and wait for connection
  DEBUG_BEGIN(115200);

  // Initialize 7-segment display
  setupDisplay();
  
  // Initialize I2S
  i2s.setDATA(I2S_DATA_PIN);
  i2s.setBCLK(I2S_BCLK_PIN);
  i2s.setBitsPerSample(BITS_PER_SAMPLE);
  i2s.setFrequency(SAMPLE_RATE);
  
  // Set up buffer configuration
  // setBuffers(num_buffers, buffer_size_in_words, silence_value)
  i2s.setBuffers(NUM_BUFFERS, BUFFER_SIZE, 0);
  
  // Register the callback BEFORE starting I2S
  i2s.onReceive(onI2SReceive);
  
  // Start I2S
  if (!i2s.begin()) {
    DEBUG("Failed to initialize I2S!");
    while (1);
  }
  
  DEBUG("I2S initialized successfully");
  DEBUG("Sample rate: %d Hz\n", SAMPLE_RATE);
  DEBUG("Buffer size: %d samples (%d ms)\n", BUFFER_SIZE, (BUFFER_SIZE * 1000) / SAMPLE_RATE);
  DEBUG("Update interval: %d ms\n", UPDATE_INTERVAL_MS);
  DEBUG("Buffers per update: %d\n", BUFFERS_PER_UPDATE);
  DEBUG("\nListening... (dB SPL readings every 0.5 seconds)");
  DEBUG("Time(ms), dBFS, dB SPL");
 
  lastUpdateTime = millis();
}

void loop() {
  bool buttonReading = digitalRead(BTN_PIN);
  
  // Check if button state changed
  if (buttonReading != lastButtonReading) {
    lastDebounceTime = millis();
  }
  
  // If enough time has passed (debounce)
  if ((millis() - lastDebounceTime) > DEBOUNCE_DELAY_MS) {
    if (buttonReading != buttonState) {
      buttonState = buttonReading;
      if (buttonState == LOW) {
        DEBUG("pressed\r\n");
        mode = 1;
      } else {
        DEBUG("released\r\n");
        displayTime = millis();
        mode = 2;
      }
    }
  }
  
  // Store previous button reading
  lastButtonReading = buttonReading;

  // Check if a buffer is ready
  if (bufferReady) {
    bufferReady = false;
    
    // Read the buffer data
    size_t bytesRead = i2s.read((uint8_t*)processingBuffer, BUFFER_SIZE * 2 * sizeof(int32_t));
    
    // Accumulate sum of squares from left channel only
    for (int i = 0; i < BUFFER_SIZE * 2; i += 2) {  
      int64_t sample = processingBuffer[i];
      // Normalize to avoid overflow: divide by 256 before squaring
      int64_t normalized = sample >> 8;  // Divide by 256
      sumOfSquares += (normalized * normalized);
    }
    
    samplesAccumulated += BUFFER_SIZE;
    buffersAccumulated++;
    
    // Check if it's time to calculate and report dB
    unsigned long currentTime = millis();
    if (currentTime - lastUpdateTime >= UPDATE_INTERVAL_MS) {
      
      if (samplesAccumulated > 0) {
        double meanSquare = (double)sumOfSquares / (double)samplesAccumulated;
        double rms = sqrt(meanSquare);
        
        // Account for the normalization (we divided by 256, so multiply back)
        rms = rms * 256.0;
        
        // Convert to dBFS
        double dbFS;
        if (rms > 0) {
          dbFS = 20.0 * log10(rms / FULL_SCALE_32BIT);
        } else {
          dbFS = -INFINITY;
        }
        
        // Convert to dB SPL using microphone sensitivity
        double dbSPL = dbFS + MIC_OFFSET_DB;

        // Track peak in recording mode
        if (mode == 1) {
          if (dbSPL > peakDbSPL) {
            peakDbSPL = dbSPL;
          }
        }

        // Round to nearest dB
        int disp_dbSPL = (int)round(dbSPL);

        // Convert SPL to LED brightness level
        uint8_t brightness = dbToPWM(dbSPL);

        // Display based on mode
        switch (mode) {
          case 0:
            updateDisplay(disp_dbSPL);
            analogWrite(EYE_L_PIN, brightness);
            analogWrite(EYE_R_PIN, brightness);
            break;
          case 1:
            displayDashes();
            analogWrite(EYE_L_PIN, brightness);
            analogWrite(EYE_R_PIN, brightness);
            break;
          case 2:
            if ((millis() - displayTime) > PEAK_DISPLAY_HOLD_MS) {
              DEBUG("Max SPL: %.1f\r\n", peakDbSPL);
              peakDbSPL = 0;
              mode = 0;
            }
            updateDisplay(peakDbSPL);
            analogWrite(EYE_L_PIN, 0);
            analogWrite(EYE_R_PIN, 0);
            break;
          default:
            break;
        }

        // Print results
        DEBUG("Mode: %u, PWM: %u, dB SPL: %.1f\r\n", mode, brightness, dbSPL);
        
        // Reset accumulators for next measurement period
        sumOfSquares = 0;
        samplesAccumulated = 0;
        buffersAccumulated = 0;
      }
      
      lastUpdateTime = currentTime;
    }
  }
}

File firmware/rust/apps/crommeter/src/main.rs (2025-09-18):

#![no_std]
#![no_main]

// Embassy: HAL imports
use embassy_rp::bind_interrupts;
use embassy_rp::gpio;
use embassy_rp::peripherals::USB;
use embassy_rp::usb::{Driver, InterruptHandler};

// Embassy: main executor
use embassy_executor::Spawner;

// Embassy: timer
use embassy_time::Timer;

// Let panic_probe handle our panic routine
use panic_probe as _;

// Macro to bind USB interrupt handler
bind_interrupts!(struct Irqs {
    USBCTRL_IRQ => InterruptHandler<USB>;
});

// Task: handle USB logging
#[embassy_executor::task]
async fn logger_task(driver: Driver<'static, USB>) {
    embassy_usb_logger::run!(1024, log::LevelFilter::Debug, driver);
}

// Task: blink the LED if the button is pressed
#[embassy_executor::task]
async fn blink_led_task(mut pin: gpio::Output<'static>) {
    loop {
        // Turn on LED
        pin.set_high();
        log::info!("LED is on");
        Timer::after_millis(250).await;

        // Turn off LED
        pin.set_low();
        log::info!("LED is off");
        Timer::after_millis(250).await;
    }
}

#[embassy_executor::main]
async fn main(spawner: Spawner) {
    // Initialize embassy HAL
    let p = embassy_rp::init(Default::default());

    // Initialize USB driver and task
    let usb_driver = Driver::new(p.USB, Irqs);
    let _ = spawner.spawn(logger_task(usb_driver));

    // Create a new output pin
    let led_pin = gpio::Output::new(p.PIN_15, gpio::Level::Low);

    // Spawn blink task
    spawner.spawn(blink_led_task(led_pin)).unwrap();

    // Keep main alive
    loop {
        Timer::after_secs(1).await;
    }
}

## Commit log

2025-09-20 Got some help from Claude. Some progress in getting the ping-pong buffer working.
    [crommeter.kicad_pcb, crommeter.kicad_sch]
2025-09-22 Initial KiCad schematic done
    [crommeter.kicad_sch]
2025-09-23 Finished schematic. Parts placed in general areas.
    [crommeter.kicad_pcb]
2025-09-24 Added artwork
    [crommeter.kicad_pcb, crommeter.kicad_sch]
2025-09-26 Mostly finished layout
    [crommeter.kicad_pcb]
2025-09-27 Generated gerbers
    [crommeter-B_Cu.gbr, crommeter-B_Mask.gbr, crommeter-B_Paste.gbr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]
2025-09-30 Created gerbers
2025-10-15 Added BOM
    [BOM.csv, crommeter.kicad_sch]

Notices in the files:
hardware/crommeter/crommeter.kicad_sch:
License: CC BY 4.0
